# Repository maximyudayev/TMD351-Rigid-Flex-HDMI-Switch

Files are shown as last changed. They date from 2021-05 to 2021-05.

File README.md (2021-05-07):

# Rigid-Flex HDMI Switch - TI TMDS351
This HDMI switch board was built as part of my Hardware Design course at KU Leuven - Campus GroupT in academic year 2020-2021, taught by the awesome Gorik :wink:

PCB front side:
PCB front side

PCB back side:
PCB back side

Mechanical layer details:
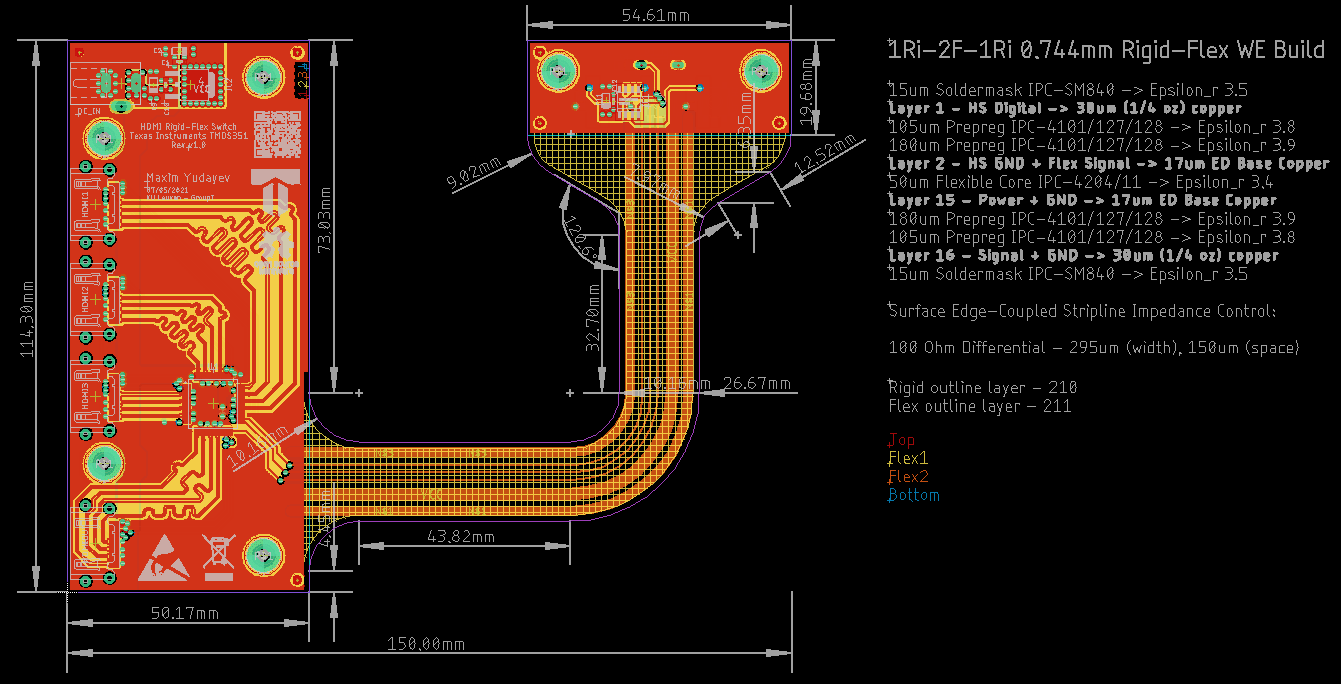
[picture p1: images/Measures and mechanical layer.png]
Mechanical layer details


100 Ohm differential trace width:
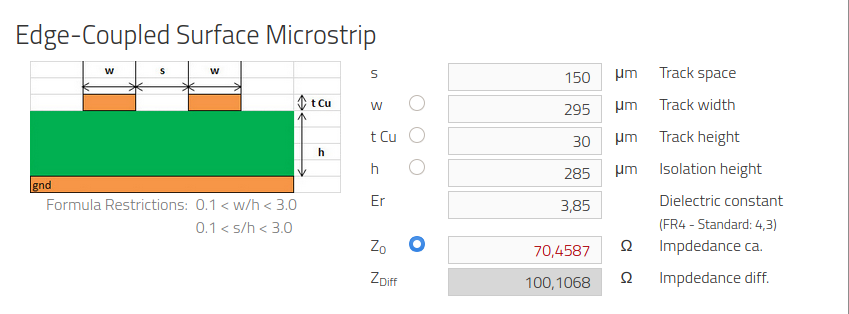
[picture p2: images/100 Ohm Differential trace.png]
100 Ohm differential trace width


All the design files are under GPL3 and can be freely used for personal projects where this device can be of use.

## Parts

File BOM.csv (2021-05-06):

Qty | Value | Device | Package | Parts | Description
1 |  | DCJ0303 | DCJ0303 | DC_IN | DC POWER JACK
4 |  | R-EU_R0805 | R0805 | R7, R8, R9, R10 | RESISTOR, European symbol
1 |  | SW_DIP-1 | EDG-01 | SEL_EQ | DIP SWITCH
2 | 100n | C-EUC0402 | C0402 | C10, C12 | CAPACITOR, European symbol
1 | 100n | C0402 | 0402 | C8
1 | 10n | C-EUC0402 | C0402 | C1 | CAPACITOR, European symbol
6 | 10n | C0402 | 0402 | C3, C4, C5, C6, C7, C13
3 | 47k | R0402 | 0402 | R2, R3, R4
3 | 47u | CPOL-EUSMCA | SMC_A | C2, C9, C11 | POLARIZED CAPACITOR, European symbol
1 | 4k02 | R0402 | 0402 | R1
2 | 4k7 | R0402 | 0402 | R5, R6
6 | FIDUCIAL" | FIDUCIAL" | FIDUCIAL_1MM | FID1, FID2, FID3, FID4, FID5, FID6 | Fiducial Alignment Points
4 | HDMI-A | HDMI-A | HDMI_A | HDMI1, HDMI2, HDMI3, HDMIOUT | Horizonal HDMI type A" jack"
1 | LD117ADT-TR | LD117ADT-TR | DPACK | IC2 | Low drop fixed and adjustable positive voltage regulators 1 A
6 | MOUNTINGHOLE3.0 | MOUNTINGHOLE3.0 | MOUNTINGHOLE_3.0_PLATED | U$1, U$2, U$31, U$32, U$33, U$34 | Mounting Hole
1 | PIC12F675SN | PIC12F675SN | SO-08 | IC1 | 8-Pin FLASH-Based 8-Bit CMOS Microcontroller
3 | SKHMPSE010 | SKHMPSE010 | SKHMPXE010 | SEL_H1, SEL_H2, SEL_H3 | 6.2 X 6.5mm TACT Switch (SMD)
1 | TMDS351TQFP64 | TMDS351TQFP64 | QFP50P1200X1200X120-64 | U1

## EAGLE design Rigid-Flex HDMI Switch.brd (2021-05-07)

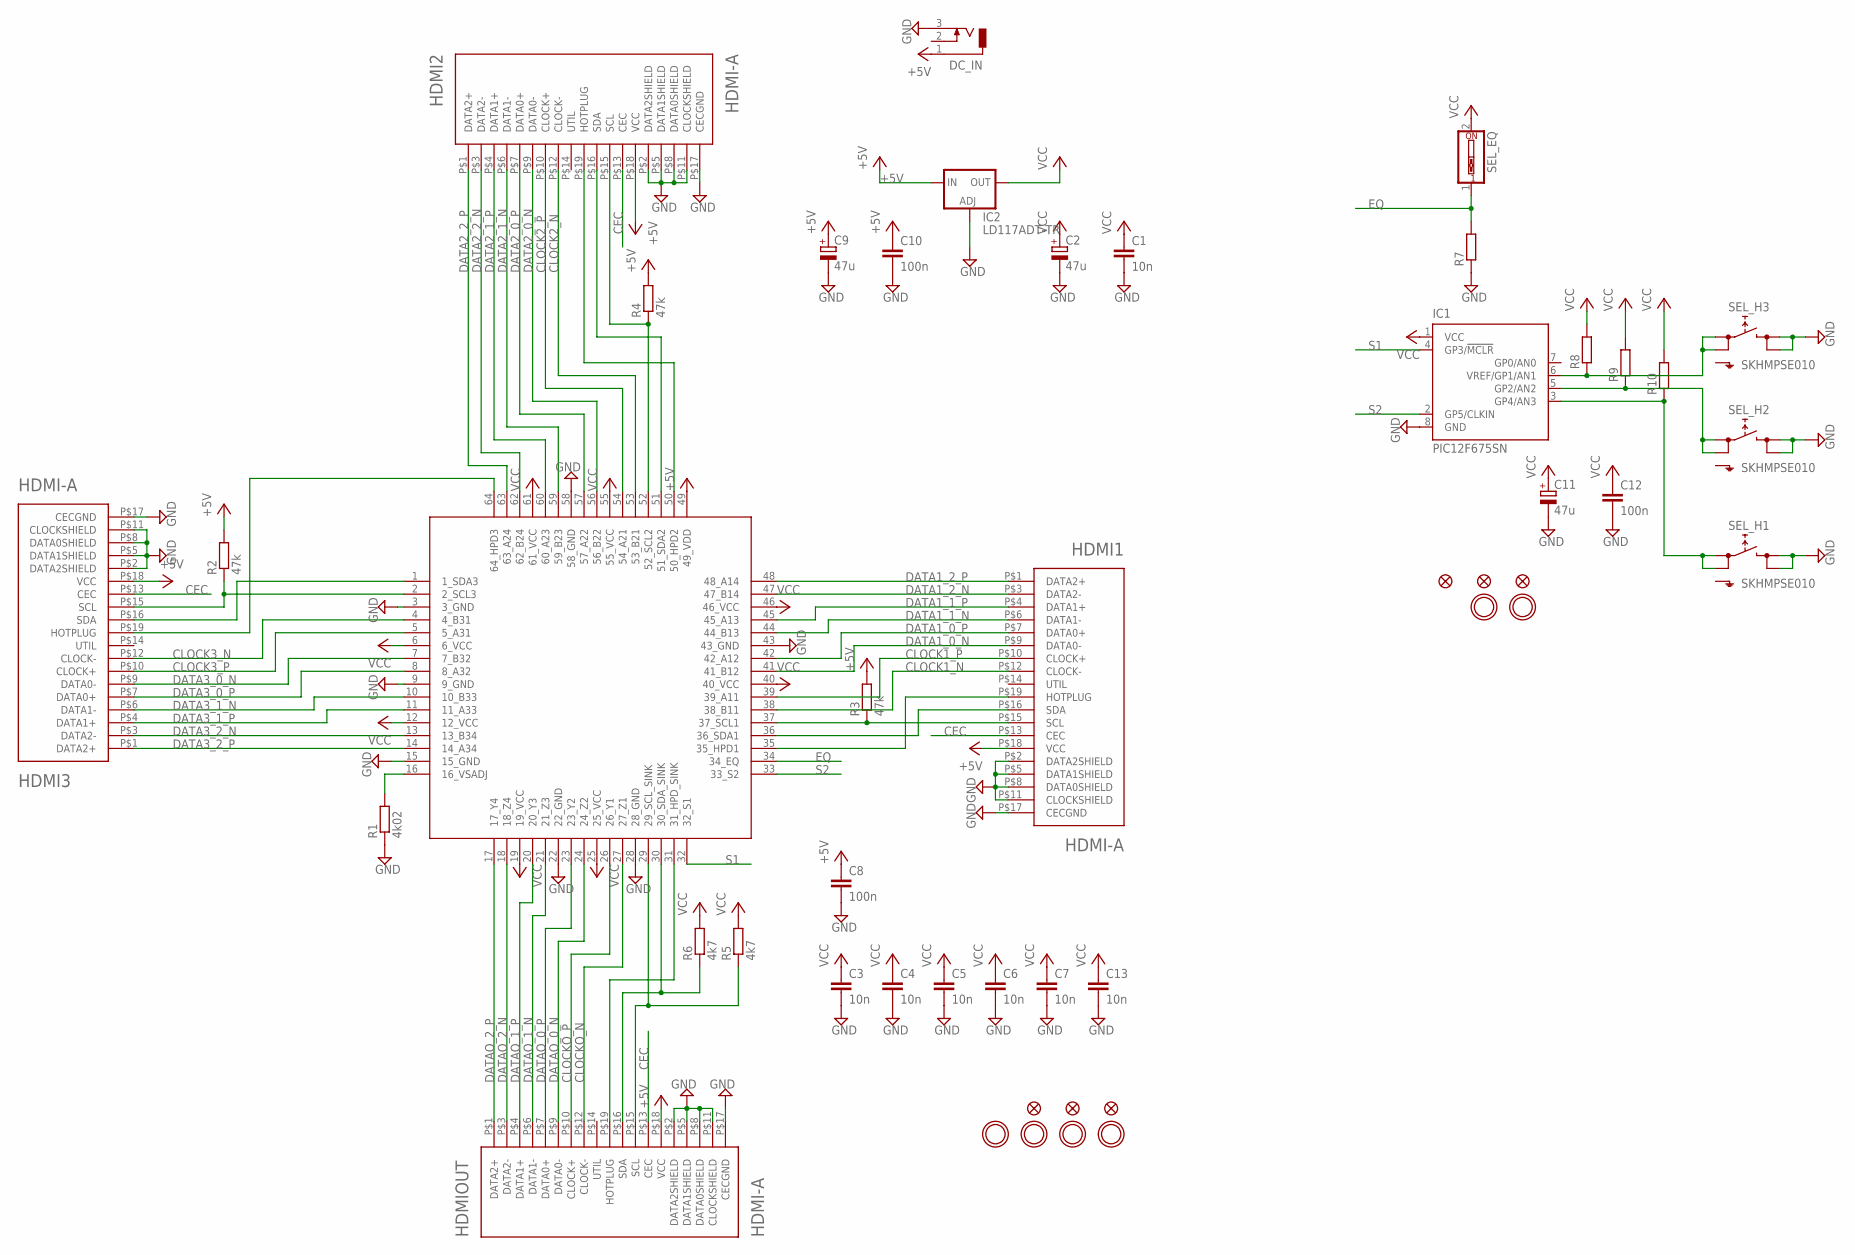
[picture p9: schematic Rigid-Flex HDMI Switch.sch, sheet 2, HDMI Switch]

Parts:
C1: 10n; C0402
C2, C9, C11: 47u; SMC_A
C3, C4, C5, C6, C7, C13: 10n; 0402
C8: 100n; 0402
C10, C12: 100n; C0402
DC_IN: DCJ0303
FID1, FID2, FID3, FID4, FID5, FID6: FIDUCIAL""; FIDUCIAL_1MM
HDMI1, HDMI2, HDMI3: HDMI-A; HDMI_A
HDMIOUT: HDMI-A; HDMI_A
IC1: PIC12F675SN; SO-08
IC2: LD117ADT-TR; DPACK
R1: 4k02; 0402
R2, R3, R4: 47k; 0402
R5, R6: 4k7; 0402
R7, R8, R9, R10: R-EU_R0805; R0805
SEL_EQ: SW_DIP-1; EDG-01
SEL_H1, SEL_H2, SEL_H3: SKHMPSE010; SKHMPXE010
U1: TMDS351TQFP64; QFP50P1200X1200X120-64
U$1, U$2, U$31, U$32, U$33, U$34: MOUNTINGHOLE3.0; MOUNTINGHOLE_3.0_PLATED

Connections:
+5V: C8.1, C9.+, C10.1, DC_IN.1, HDMI1.P$18 (VCC), HDMI2.P$18 (VCC), HDMI3.P$18 (VCC), HDMIOUT.P$18 (VCC), IC2.3 (IN), R2.2, R3.2, R4.2, U1.49 (49_VDD)
CEC: HDMI1.P$13 (CEC), HDMI2.P$13 (CEC), HDMI3.P$13 (CEC), HDMIOUT.P$13 (CEC)
CLOCK1_N: HDMI1.P$12 (CLOCK-), U1.38 (38_B11)
CLOCK1_P: HDMI1.P$10 (CLOCK+), U1.39 (39_A11)
CLOCK2_N: HDMI2.P$12 (CLOCK-), U1.53 (53_B21)
CLOCK2_P: HDMI2.P$10 (CLOCK+), U1.54 (54_A21)
CLOCK3_N: HDMI3.P$12 (CLOCK-), U1.4 (4_B31)
CLOCK3_P: HDMI3.P$10 (CLOCK+), U1.5 (5_A31)
CLOCKO_N: HDMIOUT.P$12 (CLOCK-), U1.27 (27_Z1)
CLOCKO_P: HDMIOUT.P$10 (CLOCK+), U1.26 (26_Y1)
DATA1_0_N: HDMI1.P$9 (DATA0-), U1.41 (41_B12)
DATA1_0_P: HDMI1.P$7 (DATA0+), U1.42 (42_A12)
DATA1_1_N: HDMI1.P$6 (DATA1-), U1.44 (44_B13)
DATA1_1_P: HDMI1.P$4 (DATA1+), U1.45 (45_A13)
DATA1_2_N: HDMI1.P$3 (DATA2-), U1.47 (47_B14)
DATA1_2_P: HDMI1.P$1 (DATA2+), U1.48 (48_A14)
DATA2_0_N: HDMI2.P$9 (DATA0-), U1.56 (56_B22)
DATA2_0_P: HDMI2.P$7 (DATA0+), U1.57 (57_A22)
DATA2_1_N: HDMI2.P$6 (DATA1-), U1.59 (59_B23)
DATA2_1_P: HDMI2.P$4 (DATA1+), U1.60 (60_A23)
DATA2_2_N: HDMI2.P$3 (DATA2-), U1.62 (62_B24)
DATA2_2_P: HDMI2.P$1 (DATA2+), U1.63 (63_A24)
DATA3_0_N: HDMI3.P$9 (DATA0-), U1.7 (7_B32)
DATA3_0_P: HDMI3.P$7 (DATA0+), U1.8 (8_A32)
DATA3_1_N: HDMI3.P$6 (DATA1-), U1.10 (10_B33)
DATA3_1_P: HDMI3.P$4 (DATA1+), U1.11 (11_A33)
DATA3_2_N: HDMI3.P$3 (DATA2-), U1.13 (13_B34)
DATA3_2_P: HDMI3.P$1 (DATA2+), U1.14 (14_A34)
DATAO_0_N: HDMIOUT.P$9 (DATA0-), U1.24 (24_Z2)
DATAO_0_P: HDMIOUT.P$7 (DATA0+), U1.23 (23_Y2)
DATAO_1_N: HDMIOUT.P$6 (DATA1-), U1.21 (21_Z3)
DATAO_1_P: HDMIOUT.P$4 (DATA1+), U1.20 (20_Y3)
DATAO_2_N: HDMIOUT.P$3 (DATA2-), U1.18 (18_Z4)
DATAO_2_P: HDMIOUT.P$1 (DATA2+), U1.17 (17_Y4)
EQ: R7.2, SEL_EQ.1, U1.34 (34_EQ)
GND: C1.2, C2.-, C3.2, C4.2, C5.2, C6.2, C7.2, C8.2, C9.-, C10.2, C11.-, C12.2, C13.2, DC_IN.3, HDMI1.P$2 (DATA2SHIELD), HDMI1.P$5 (DATA1SHIELD), HDMI1.P$8 (DATA0SHIELD), HDMI1.P$11 (CLOCKSHIELD), HDMI1.P$17 (CECGND), HDMI2.P$2 (DATA2SHIELD), HDMI2.P$5 (DATA1SHIELD), HDMI2.P$8 (DATA0SHIELD), HDMI2.P$11 (CLOCKSHIELD), HDMI2.P$17 (CECGND), HDMI3.P$2 (DATA2SHIELD), HDMI3.P$5 (DATA1SHIELD), HDMI3.P$8 (DATA0SHIELD), HDMI3.P$11 (CLOCKSHIELD), HDMI3.P$17 (CECGND), HDMIOUT.P$2 (DATA2SHIELD), HDMIOUT.P$5 (DATA1SHIELD), HDMIOUT.P$8 (DATA0SHIELD), HDMIOUT.P$11 (CLOCKSHIELD), HDMIOUT.P$17 (CECGND), IC1.8 (GND), IC2.1 (ADJ), R1.1, R7.1, SEL_H1.3 (2.1), SEL_H1.4 (2.2), SEL_H2.3 (2.1), SEL_H2.4 (2.2), SEL_H3.3 (2.1), SEL_H3.4 (2.2), U1.3 (3_GND), U1.9 (9_GND), U1.15 (15_GND), U1.22 (22_GND), U1.28 (28_GND), U1.43 (43_GND), U1.58 (58_GND)
unnamed: HDMI3.P$19 (HOTPLUG), U1.64 (64_HPD3)
unnamed: HDMI2.P$19 (HOTPLUG), U1.50 (50_HPD2)
unnamed: HDMI1.P$19 (HOTPLUG), U1.35 (35_HPD1)
unnamed: HDMIOUT.P$19 (HOTPLUG), U1.31 (31_HPD_SINK)
unnamed: HDMI3.P$16 (SDA), U1.1 (1_SDA3)
unnamed: HDMI3.P$15 (SCL), R2.1, U1.2 (2_SCL3)
unnamed: HDMI2.P$16 (SDA), U1.51 (51_SDA2)
unnamed: HDMI2.P$15 (SCL), R4.1, U1.52 (52_SCL2)
unnamed: HDMI1.P$15 (SCL), R3.1, U1.37 (37_SCL1)
unnamed: HDMI1.P$16 (SDA), U1.36 (36_SDA1)
unnamed: HDMIOUT.P$16 (SDA), R6.1, U1.30 (30_SDA_SINK)
unnamed: HDMIOUT.P$15 (SCL), R5.1, U1.29 (29_SCL_SINK)
unnamed: R1.2, U1.16 (16_VSADJ)
unnamed: IC1.6 (VREF/GP1/AN1), R8.1, SEL_H3.1 (1.1), SEL_H3.2 (1.2)
unnamed: IC1.5 (GP2/AN2), R9.1, SEL_H2.1 (1.1), SEL_H2.2 (1.2)
unnamed: IC1.3 (GP4/AN3), R10.1, SEL_H1.1 (1.1), SEL_H1.2 (1.2)
S1: IC1.4 (GP3/!MCLR), U1.32 (32_S1)
S2: IC1.2 (GP5/CLKIN), U1.33 (33_S2)
VCC: C1.1, C2.+, C3.1, C4.1, C5.1, C6.1, C7.1, C11.+, C12.1, C13.1, IC1.1 (VCC), IC2.4 (OUT), R5.2, R6.2, R8.2, R9.2, R10.2, SEL_EQ.2, U1.6 (6_VCC), U1.12 (12_VCC), U1.19 (19_VCC), U1.25 (25_VCC), U1.40 (40_VCC), U1.46 (46_VCC), U1.55 (55_VCC), U1.61 (61_VCC)

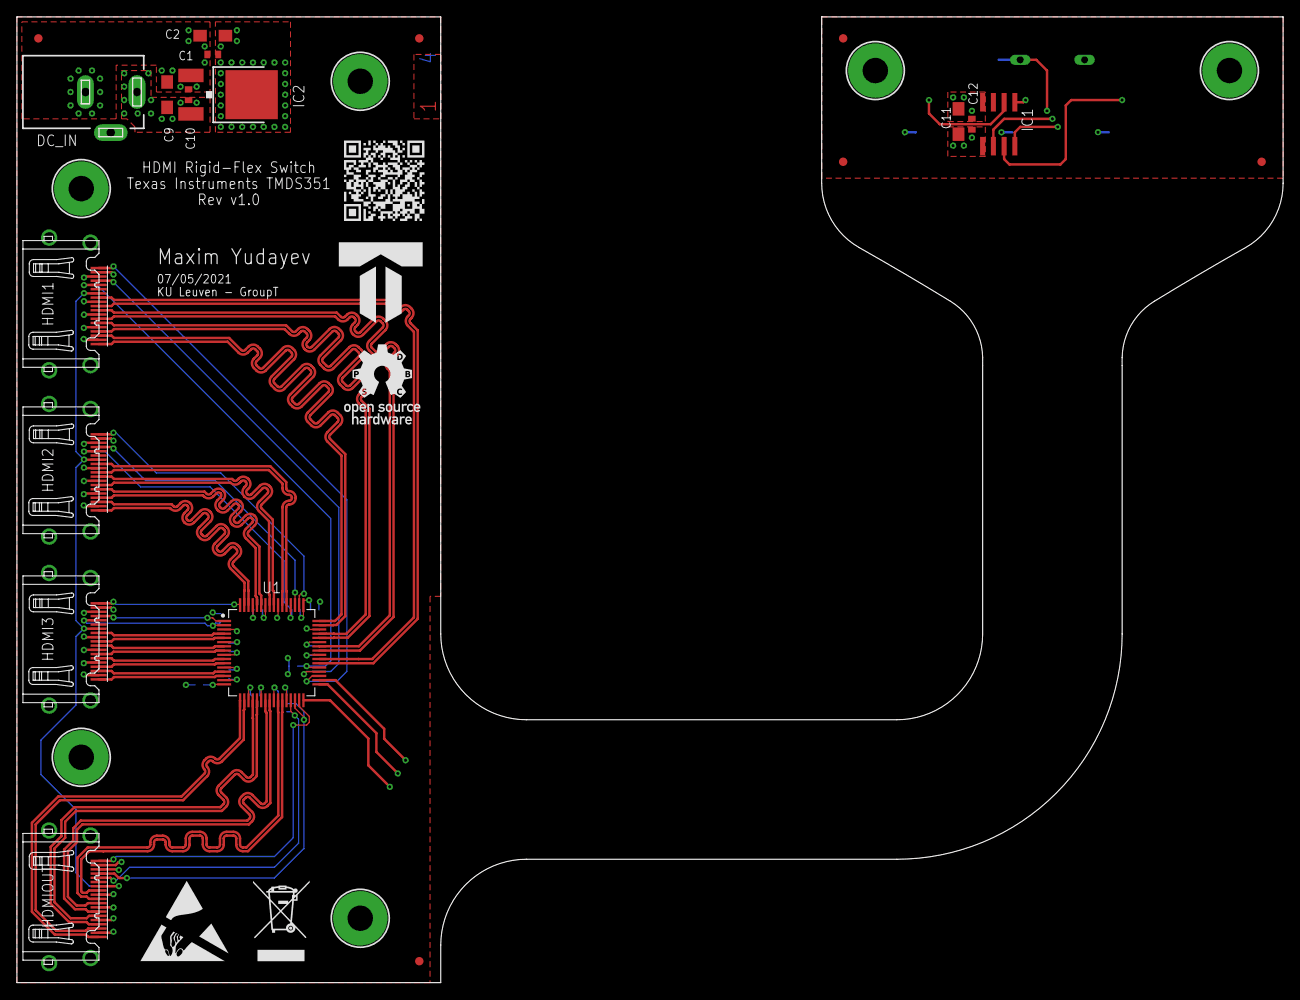
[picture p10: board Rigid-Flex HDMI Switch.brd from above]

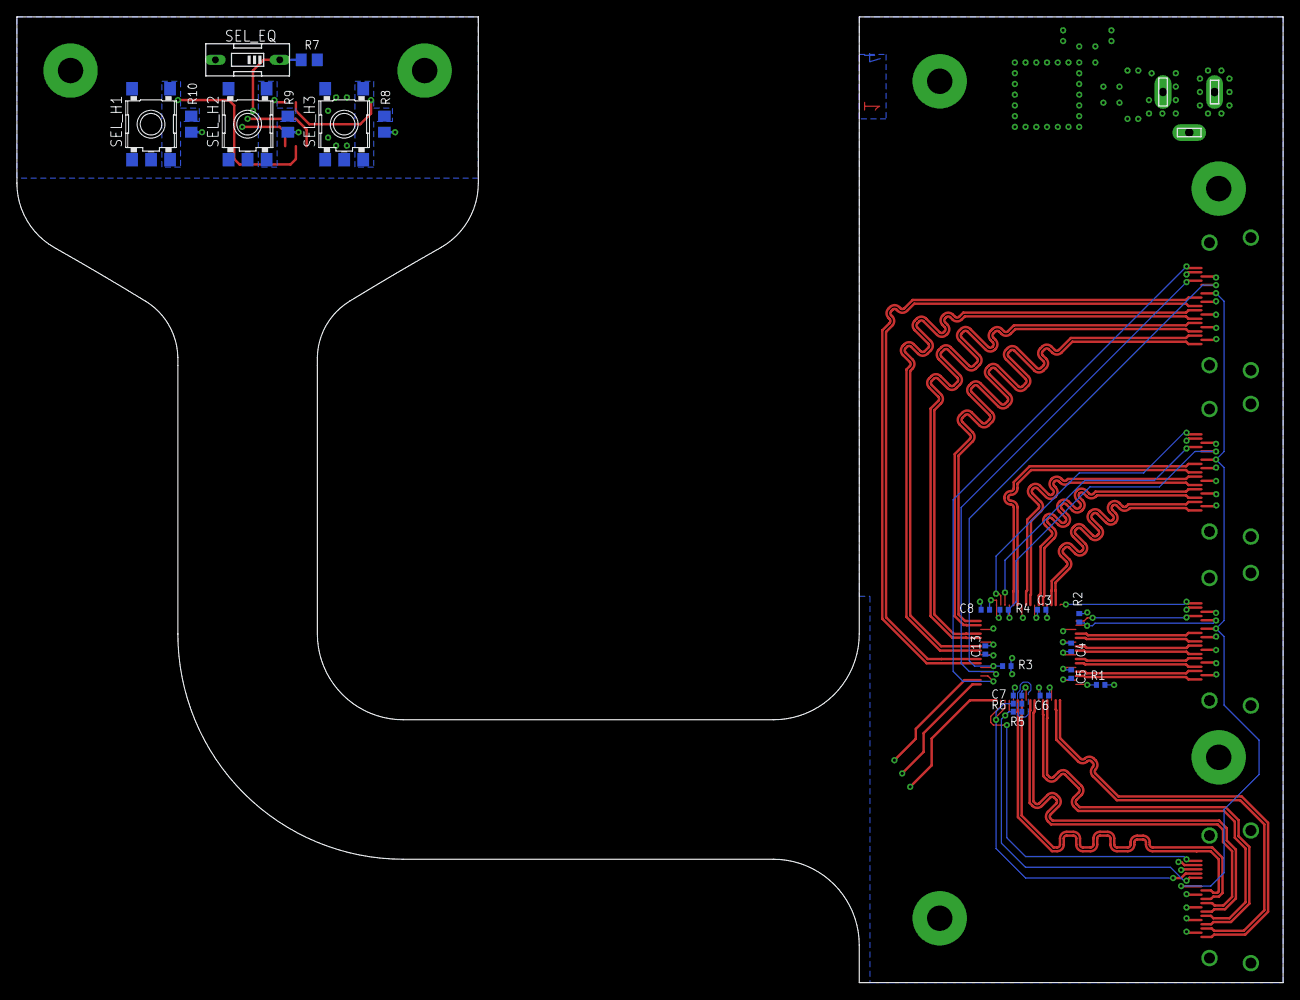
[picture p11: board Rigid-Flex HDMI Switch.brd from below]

Board: 4 copper layers, 149.9 x 114.3 mm, 47 parts (21 on the bottom side), 55 nets.

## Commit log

2021-05-06 Full PCB design, images, BOM, misc
    [BOM.csv, Rigid-Flex HDMI Switch.brd, Rigid-Flex HDMI Switch.sch]
2021-05-07 Added gerbers, rigid-flex outline, CAM and images
    +: Custom CAM job file for WE 1Ri-2F-1Ri buildup to accomodate
    separate rigid and flex outlines
    +: Updated images and README to display most recent information
    [Rigid-Flex HDMI Switch.brd, Rigid-Flex HDMI Switch.sch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]

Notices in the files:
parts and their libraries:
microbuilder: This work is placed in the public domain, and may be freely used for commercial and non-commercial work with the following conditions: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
